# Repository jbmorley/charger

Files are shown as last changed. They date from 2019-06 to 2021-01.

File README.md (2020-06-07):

# Charger

Qi charger for iPhone, AirPods, and Apple Watch

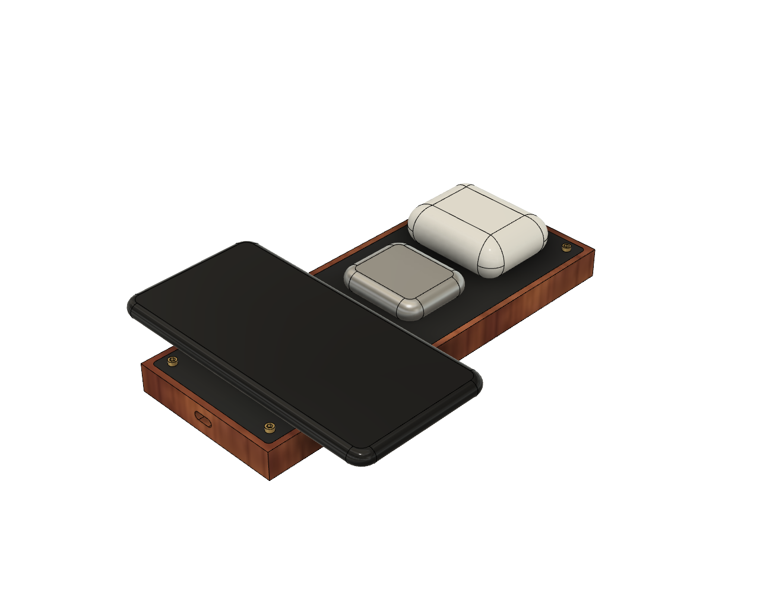
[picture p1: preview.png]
Preview


# Hardware

## Qi Charger PCB Mounting

### Bolts (Nylon) x 4

| Feature | Calculation (mm) | Size (mm) |
| --- | --- | --- |
| Head Diameter	  | 6.0 | |
| Head Depth | 2.0 | |
| Thread Diameter | 3.0 | |
| Thread Length | 2.5 + 5.0 | |

### Nuts (Nylon) x 4

| Feature | Calculation (mm) | Size (mm) |
| --- | --- | --- |
| Thread Diameter | 3.0 | |
| Depth | 2.0 | |

## USB-C PCB Mounting

### Bolts (Nylon) x 4

| Feature | Calculation (mm) | Size (mm) |
| --- | --- | --- |
| Head Diameter | 5.0 | |
| Head Depth | 2.0 | |
| Thread Diameter | 3.0 | |
| Thread Length | 4.0 + 3.5 | |

_N.B. The thread diameter here seems off; I don’t believe these are M3 boards. Either that, or the measurements on the Qi charger PCBs are off._

_No washers are required as the board needs to sit flush with the case to ensure the USB-C port aligns correctly._

## Case Mounting

### Bolts (Brass) x 4

| Feature | Calculation (mm) | Size (mm) |
| --- | --- | --- |
| Head Diameter | 6.0 | |
| Head Depth | 4.0 | |
| Thread Diameter | 3.0 | |
| Thread Length | 13.5 + 1.0 + 4.0 | 18.0 |

_Trying with a 16.0 mm screw in the first instance._

https://www.mcmaster.com/90349A106

### Nuts (Brass) x 4

| Feature | Calculation (mm) | Size (mm) |
| --- | --- | --- |
| Thread Diameter | 3.0 | |
| Depth | 2.0 | |

https://www.mcmaster.com/90690A037

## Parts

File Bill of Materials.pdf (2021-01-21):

Part | Supplier | Link | Cost | Quantity | Setup Costs | Shipping | Total Cost | Order #1
3D Printed Case | Shapeways | $51.01 | 1 | $4.99 | $56.00 Yes
3D Printed Foot | Shapeways | $7.50 | 2 | $15.00 Yes
Universal Qi Wireless Charging Transmitter | Adafruit | https://www.adafruit.com/product/2162 | $26.95 | 2 | $6.40 | $60.30 Yes
Adafruit USB C Breakout Board - Downstream Connection | Adafruit | https://www.adafruit.com/product/4090 | $2.95 | 1 | $2.95 Yes
Brass Socket Head Screw M3 x 0.50 mm Thread, 16 mm Long McMaster-Carr https://www.mcmaster.com/90349A106 | $4.40 | 4 | $7.67 | $25.27 Yes
Brass Hex Nut M3 x 0.5 mm Thread | McMaster-Carr https://www.mcmaster.com/90690A037 | $0.06 | 2 | $0.13 Yes
Apple Watch Magnetic Charging Cable (0.3m) | Apple | https://www.apple.com/shop/product/MX2G2AM/A/apple-watch-magnetic-charging-cable-03m?fnode=83 $31.47 | 1 | $31.47
Laser-Cut Top Plate | Ponoko | $2.82 | 1 | $9.00 | $11.82 Yes
Laser-Cut Bottom Plate | Ponoko | $2.47 | 1 | $2.47 Yes
Laser-Cut Fabric Top Black Ultrasuede | Ponoko | $2.65 | 1 | $2.65 Yes

N.B. This sheet is missing internal bolts and washers

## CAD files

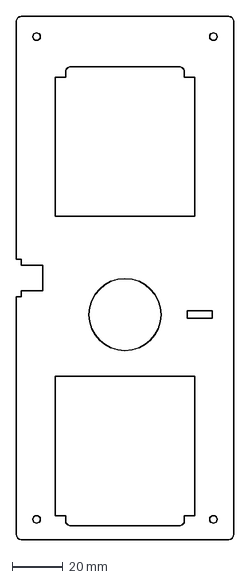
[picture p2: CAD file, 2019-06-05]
iterations/2019-06-05-acrylic/layer-2.dxf
86.0 x 206.9 mm

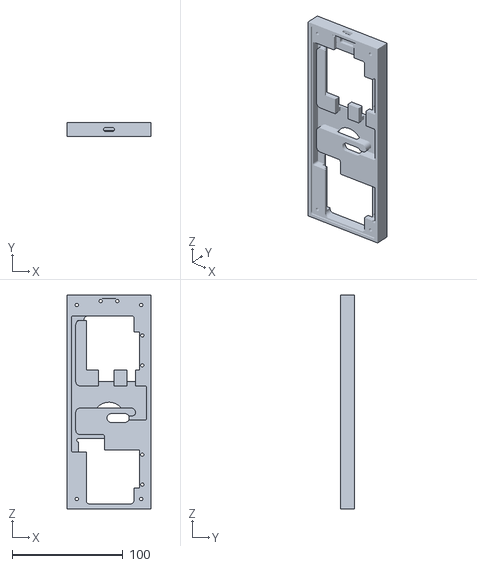
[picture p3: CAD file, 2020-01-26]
iterations/2020-03-14-blake/case.stl
76.0 x 13.0 x 192.9

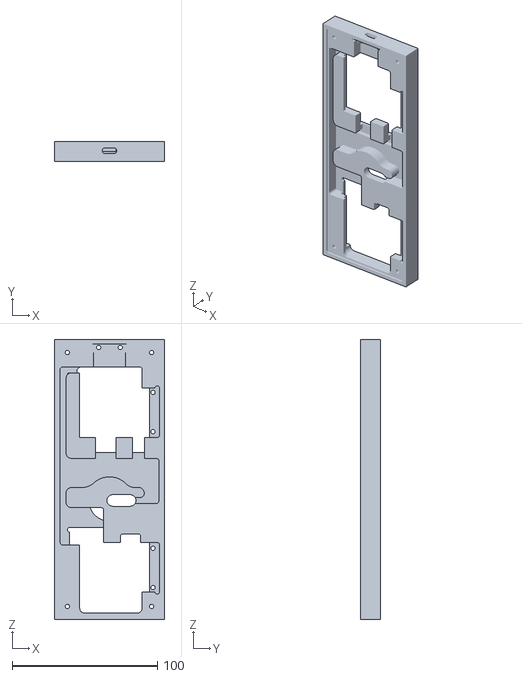
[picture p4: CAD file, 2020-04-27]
iterations/2020-04-27-terrence/case-shapeways-versatile-plastic.stl
76.0 x 14.0 x 192.9

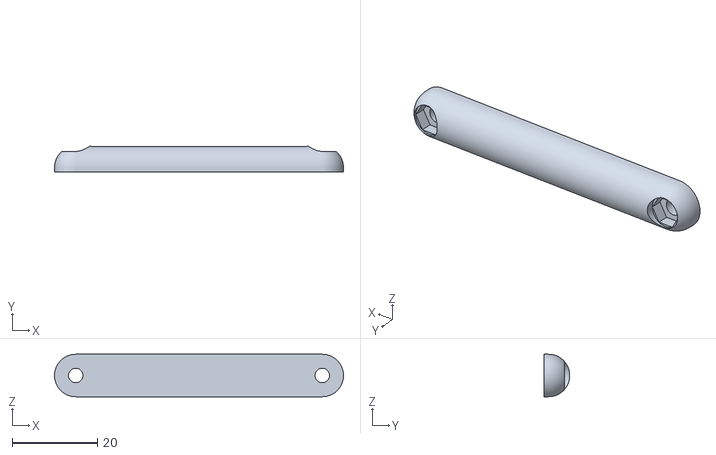
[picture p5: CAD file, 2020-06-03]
iterations/2020-06-03-johannes/foot-shapeways-versatile-plastic.stl
68.0 x 6.00 x 10.0

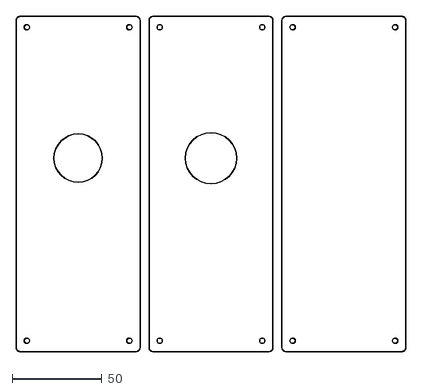
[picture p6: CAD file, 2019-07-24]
wood/adjusted/top-narrow-variants.dxf
217.2 x 186.9

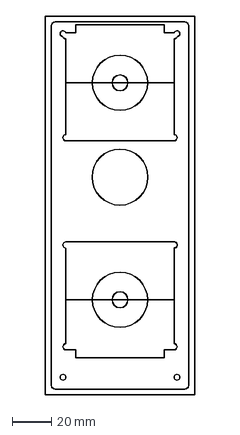
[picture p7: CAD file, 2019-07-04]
wood/body/dxf/topcuts.dxf
76.0 x 192.9 mm

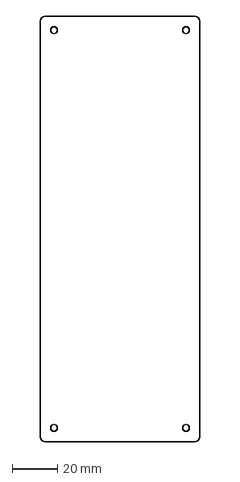
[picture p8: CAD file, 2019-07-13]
wood/bottom/base.dxf
70.0 x 186.9 mm

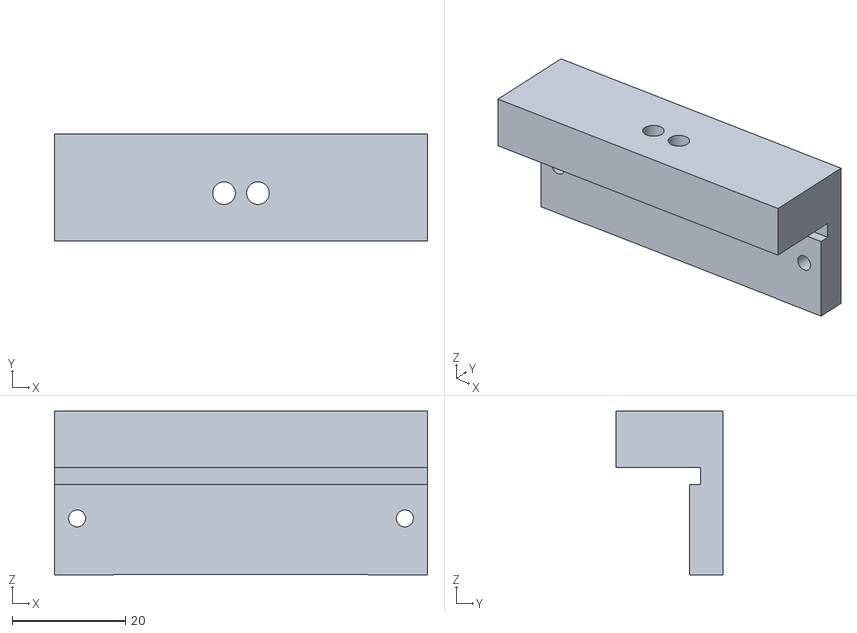
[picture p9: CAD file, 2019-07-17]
wood/drilling-jig/usb-port-drill-jig.stl
66.0 x 19.0 x 29.0

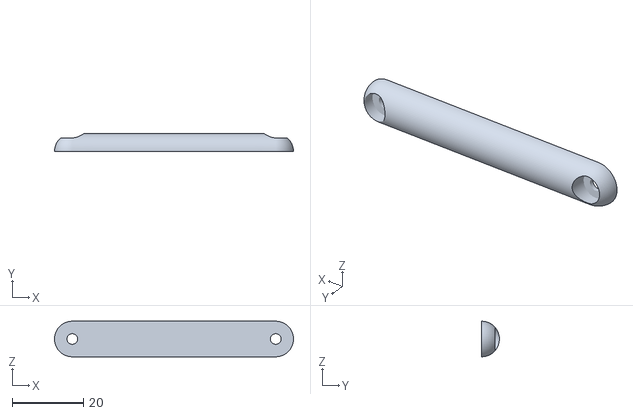
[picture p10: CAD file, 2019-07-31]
wood/feet/foot-adjusted.stl
67.2 x 5.00 x 10.0

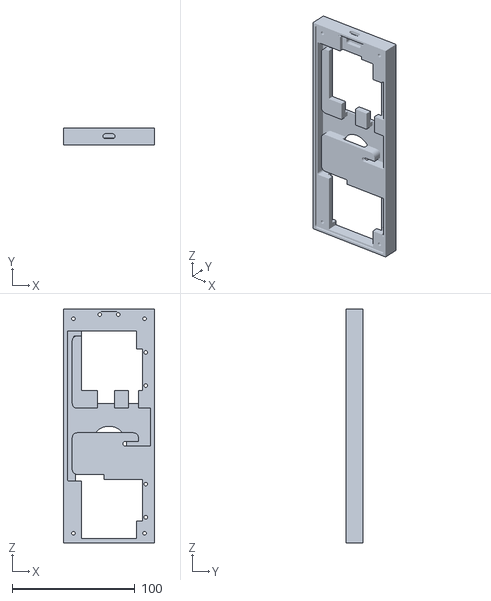
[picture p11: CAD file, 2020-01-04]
wood/shapeways-base-versatile-plastic.stl
74.0 x 13.5 x 190.9

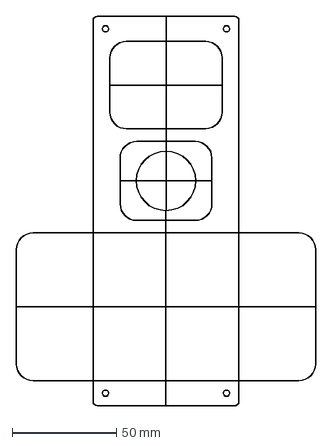
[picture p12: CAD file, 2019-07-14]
wood/top/top-center-points.dxf
143.6 x 186.9 mm

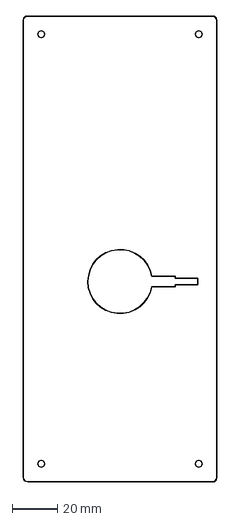
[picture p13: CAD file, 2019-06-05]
iterations/2019-06-05-acrylic/layer-0.dxf
86.0 x 206.9 mm

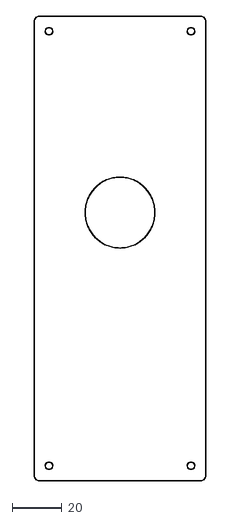
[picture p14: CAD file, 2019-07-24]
wood/adjusted/adjusted.dxf
69.0 x 186.9

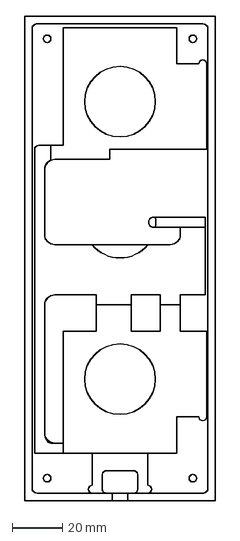
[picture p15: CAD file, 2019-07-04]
wood/body/dxf/bottom-mark-3.dxf
76.0 x 192.9 mm

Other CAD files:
iterations/2020-04-27-terrence/foot.stl
iterations/2020-06-03-johannes/case-shapeways-versatile-plastic.stl
wood/top/top-small-diameter.dxf
iterations/2019-06-05-acrylic/layer-3.dxf
iterations/2019-06-05-acrylic/layer-1.dxf
iterations/2019-06-05-acrylic/layer-4.dxf
wood/body/dxf/botcuts.dxf
wood/body/dxf/bottom-cuts.dxf
wood/body/dxf/top-cuts.dxf
wood/top/top.dxf

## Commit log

2019-06-03 First DXF file
    [layer-0.dxf]
2019-06-05 Update the DXF files with the new puck dimensions.
    [layer-0.dxf, layer-1.dxf, layer-2.dxf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]
2019-07-03 Move the laser cut models into a separate director
    [layer-0.dxf, layer-1.dxf, layer-2.dxf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]
2019-07-03 Add the latest export CNC router files to the project
    [bottom-cuts.dxf, top-cuts.dxf]
2019-07-03 Add the latest tap files for the 13mm thick wood
2019-07-04 Add some more exported dxf files.
    [botcuts.dxf, bottom-mark-3.dxf]
2019-07-04 Add another dxf file
    [topcuts.dxf]
2019-07-13 Renaming 'laser' to acrylic to capture the design.
    [layer-0.dxf, layer-1.dxf, layer-2.dxf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]
2019-07-13 Cleaning up the directory naming.
    [botcuts.dxf, bottom-cuts.dxf, bottom-mark-3.dxf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]
2019-07-13 Add the DXF for the top and the bottom.
    [base.dxf, top.dxf]
2019-07-13 Add a DXF for the top plate with a smaller puck diameter.
    [top-small-diameter.dxf]
2019-07-13 Add the Ponoko P2 EPS file for laser cutting the top and bottom. This file also includes a couple of templates for some leather cable ties.
2019-07-14 Rename the laser-cut file.
2019-07-14 Add a P2 laser-cut file for the top surface.
2019-07-14 Add a new DXF for the top surface with center-points.
    [top-center-points.dxf]
2019-07-17 Add the USB port drilling jig model.
    [usb-port-drill-jig.stl]
2019-07-20 Update the bed mounting (to change the relative heights?) and add the bottom carve file.
2019-07-20 Add the re-render of the bed-mounting holes.
2019-07-20 Add the tap file for the bottom PCB pocket
2019-07-20 Better ordering of the prototype cuts.
2019-07-24 Add the narrower / adjusted top and bottom plates.
    [adjusted.dxf, top-narrow-variants.dxf]
2019-07-24 Update the adjusted cut files.
2019-07-26 Add the plywood ponoko cut files.
2019-07-31 Add the model for the foot
    [foot-adjusted.stl]
2020-01-04 Add the shapeways model for the base.
    [shapeways-base-versatile-plastic.stl]
2020-01-26 Add files via upload
    3D printing model files from the first 'production run'
    [case.stl, foot.stl]
2020-03-15 Update the foot with the new hex seat for the bolt
    [foot.stl]
2020-04-27 Clean up the folder structure a little.
    [case-shapeways-versatile-plastic.stl, case.stl, foot.stl]
2020-04-27 Move the acrylic design into the iterations folder.
    [layer-0.dxf, layer-1.dxf, layer-2.dxf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]
2020-04-27 Flatten the folder structure a little.
    [layer-0.dxf, layer-1.dxf, layer-2.dxf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]
2020-06-03 Add a new iteration
    [case-shapeways-versatile-plastic.stl]
2020-06-03 Add the feet for the latest render
    [foot-shapeways-versatile-plastic.stl]
2020-06-07 Update README.md
    Remove the notes on how to cut the design with a CNC mill; the design has changed sufficiently that this no longer seems relevant.
2020-06-07 Add the additional 3d print files
    [case-shapeways-versatile-plastic.stl, foot-shapeways-versatile-plastic.stl]
